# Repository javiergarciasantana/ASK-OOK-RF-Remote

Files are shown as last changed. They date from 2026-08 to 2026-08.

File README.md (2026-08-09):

# ASK-OOK-RF-Remote
Design files for my 433MHz RF remote specifically made to fit into VW Transporter T5/ Golf MK6 2 Button key fob casing.

<p align="center">

</p>

## Introduction

The *"key"* to this project is to make a functional all-in-one remote key-fob for my VW Polo 6n2. My car came from factory with a key-fob (6N0837219AC) which only had a button for a light to help you find the door or ignition lock. Said key looked like this:

<p align="center">

</p>

Additionally, my car came with a 3rd party alarm system installed from the dealer which I assume used a 433MHz additional remote with a rolling code protocol.

Nonetheless my car only had the spare key (without the light bulb) and the old alarm control unit installed behind the driver's side headlight (non UK car). Since I did not have the knowledge or expertise at the time of buying my Polo 2nd hand (I was 18), instead of getting another remote made from the existing unit, I decided to go the cheap route and buy the Aliexpress special, a 433Mhz ASK/OOK single code receiver with 2 remotes for 7EUR. [Link to the product](https://es.aliexpress.com/item/32966630703.html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)

At the time it seemed like the right choice since I wanted nothing to do with locking and unlocking my car manually (peasant things). And for a long time it was, however the first problem I noticed is that the quality of the remotes was awful, the switches degraded like crazy and I understood later that using the same single code protocol as the garage doors was not ideal. 

The remote issue I solved by getting another kind of separate remote and to this day it works like a charm after 3 years. Also and on another note, one of the best things about the receiver is that you can pair new remotes on the fly just by pressing the pairing button next to the 13 pin connector.

[Link to the other kind of remote
](https://es.aliexpress.com/item/1005008790564347.html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)<br>

---

### What problem does it solve?

Here is an image of my current key setup:




As you can see, it doesn't look half bad, however, since I am always carrying many things in my hand and other keys (plus the keychain and remote make noise everytime I hit a road bump), I wanted an all-in-one OEM+ solution. For this I started looking at Golf MK4, MK6 & MK7 remotes and decided to go with the MK6 one. I now is rather bland but its in the middle from being too futuristic(MK7) or too dingy(MK4). 





The good thing is that all remotes can share the same HU66 blade and fit on the same kind of cylinder lock, however the transponder is not the same!!! I had to install a new ID44 chip on my new key-fob. 

[Link to the 2 button Golf MK6 key-fob](https://es.aliexpress.com/item/1005005737683184.html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)

> [!IMPORTANT]
> MK4, MK5, MK6 and MK7 Golf use different transponders, going from the ID48 to the ID88

So I guess months of my life learning PCB design bit by bit would be worth it right? 
Well, for the time being I have to say yes, it was totally worth it and I learned so much in the process and got a Unique OEM+ key for my Polo out of it.

---

### Installation of the Chinese receiver
For those of you that are curious or need a wiring diagram of the OEM installation, here is a small tutorial of how I installed the receiver into my car.

#### OEM alarm 20 Pin Harness diagram

Now here I wont go much into detail, However I have to add this: the Chinese Receiver has to be put into a specific jumper configuration to be able to operate the central pneumatic system that the Polo comes standard with. Moreover, I made the mistake to not write down the wire colors but here they are detailed pin by pin:



It's not very detailed, but simply jumping the 12v with what I wanted to actuate worked, so the receiver is most likely just a big box of relays (11v in the case of the LED for some reason unknown to me).

---

Here is a connection diagram of the pins that I used on the receiver and OEM harness:



Some of them like the automatic windows did not work correctly (it was spamming like crazy). But opening and closing is a breeze and even all 6 indicators light up (one blink means close, 2 blinks is opened). 

Lastly, the OEM alarm interior light does not work with this receiver, maybe its to do with a voltage difference.


## OTP Encoding
Now to be honest, I could have designed another receiver box/module that was rolling code and could communicate and pair with Golf MK6 key-fobs, therefore integrating the automatic roll-down/up windows function or even the interior ventilation gimmick. However i was very interested in messing with this simple protocol as an RF begginer's project, so maybe in the future something like this can be made since I preserved the PCB that came with the MK6 remote.

### What is OTP Encoding?

**OTP** stands for **One-Time Programmable**. In the context of the encoder, it means the microchip contains an internal non-volatile memory layer that is permanently burned during manufacturing at the semiconductor factory with a fixed, unchangeable **20-bit identification code**.

Older RF encoders (like the classic PT2262) required 8 to 12 physical hardware pins connected to solder jumpers or DIP switches on your PCB so you could manually set a binary address. OTP encoding eliminates all of that physical configuration. Therefore, I chose the EV1527 encoder for this project as its footprint is very small and is readily available.

[EV1527 Datasheet
](./docs/EV1527.PDF)

---

### The 20-Bit Address & Possible Combinations

Every time you press a button on an EV1527 keyfob, the chip transmits a 24-bit frame:
* **20 Bits:** Factory-programmed unique address ID
* **4 Bits:** Data bits corresponding to the 4 button inputs ($K_0, K_1, K_2, K_3$)

#### Mathematical Combinations:
$$\text{Total Address Combinations} = 2^{20} = 1,048,576$$

With over 1 million unique code combinations, the probability of the keyfob sharing the exact same address code with another device nearby is roughly 1 in 1.05 million.

---

### Why OTP Encoding is the Best Choice for the Keyfob

* **Saves Board Space & Cost:** Eliminating DIP switches or solder jumper banks drastically shrinks the PCB area—allowing us to fit the EV1527 easily on the small board layout
* **Zero Serial Management During Assembly:** You don't have to program microcontrollers or keep track of serial numbers when soldering. Every EV1527 chip off the reel is guaranteed to have a different hardcoded address straight out of the box.
* **Universal Receiver Compatibility:** Modern RF receivers (learning-code receivers like the one I have) use a simple pairing button. You press "Learn" on the receiver, press your keyfob button once, and the receiver saves your unique 20-bit ID into its memory.

---

### No Crystal Needed: The Internal Oscillator & $R_{OSC}$

The EV1527 does not require a crystal oscillator, crystal load capacitors, or an external clock source.

* **Internal RC Oscillator:** The chip uses an integrated Resistor-Capacitor (RC) oscillator circuit on the silicon die.
* **Single Resistor Control:** To set the clock speed, you simply connect a single external resistor ($R_{OSC}$) between the `OSC` pin and `VCC` (typically $300\text{ k}\Omega$ to $430\text{ k}\Omega$, with $330\text{ k}\Omega$ being the standard for $433.92\text{ MHz}$ systems).
* **How It Works:** The resistance value of $R_{OSC}$ determines the charge/discharge rate of the internal oscillator, setting the timing pulse width ($T_w$) for the transmitted ASK radio signal.

## ASK/OOK Modulation

**ASK** stands for **Amplitude Shift Keying**, and **OOK** stands for **On-Off Keying**. OOK is the simplest form of ASK modulation used in low-power wireless communication.

* **How It Works:** Rather than shifting frequencies (like FM/FSK), OOK represents digital data by turning the radio transmitter **ON** and **OFF**:
  * **Binary '1' (Mark):** The transmitter turns ON and emits a full-power $433.92\text{ MHz}$ carrier wave.
  * **Binary '0' (Space):** The transmitter turns completely OFF, emitting zero radio power ($0\text{ V}$).
* **Why It Is Popular:** Because transmitting a '0' consumes virtually zero current, OOK is extremely power-efficient. Combined with low hardware complexity, it is the ideal choice for battery-powered keyfobs and garage door openers.

---

### Switching from SYN115 to CMT2110A

#### 1. The Initial Choice: SYN115
The SYN115 was initially selected because it is a widely recognized 433 MHz ASK transmitter IC. However, reviewing its datasheet revealed that it requires a significant number of external passive components to function, including crystal load capacitors, external biasing networks, and multi-stage tuning circuits, which inflates both component cost and PCB space requirements.

* **Datasheet:** [SYN115 Datasheet](./docs/SYN113-SYN115-datasheet-version-1-1-.0.pdf)

#### 2. The Solution: CMT2110A
To keep the keyfob layout compact ($37 \times 23.4\text{ mm}$), the design was shifted to the **CMT2110A**. Thanks to its high level of internal silicon integration (integrated crystal load caps, bias circuits, and internal EEPROM power control), the entire RF section requires only:

* **2 Inductors:** 
  * $L_1$ (DC supply choke)
  * $L_2$ (Series matching inductor)
* **3 Capacitors:** 
  * $C_0$ (Power decoupling filter)
  * $C_1$ (Series DC blocking capacitor)
  * $C_2$ (Shunt harmonic filter capacitor)
* **1 Quartz Crystal:** 
  * A standard 4-pin SMD $26\text{ MHz}$ crystal package (where 1 pin carries the active clock signal to the `XTAL` pin, while the remaining grounded pins provide internal shield grounding).

* **Datasheet:** [CMT2110A Datasheet](./docs/info-rf-cmt2110a-esr.pdf)

---

### Why is 433.92 MHz Used?

The $433.92\text{ MHz}$ frequency band is the dominant standard for short-range remote controls due to four key advantages:

1. **Unlicensed ISM Band:** $433.05\text{ MHz} - 434.79\text{ MHz}$ is designated worldwide as an Industrial, Scientific, and Medical (ISM) band. Devices operating under short-range, low-duty-cycle rules can transmit without requiring expensive FCC/CE user licenses.
2. **Superior Obstacle Penetration:** Sub-1 GHz signals ($433\text{ MHz}$) have longer wavelengths ($\approx 69\text{ cm}$) compared to $2.4\text{ GHz}$ (Wi-Fi/Bluetooth, $\approx 12\text{ cm}$). This allows $433\text{ MHz}$ signals to easily penetrate walls, plastic key shells, and human hands with minimal signal attenuation.
3. **Ultra-Low Battery Consumption:** At $433.92\text{ MHz}$, simple power amplifiers consume very little current ($\approx 10 - 20\text{ mA}$ during transmission), enabling years of operation on a single CR2032 coin cell.
4. **Ideal Antenna Physical Size:** A standard quarter-wave antenna at $433\text{ MHz}$ is roughly $17\text{ cm}$, which easily scales down into compact PCB trace loop antennas suitable for handheld keyfobs while maintaining reliable range ($30 - 100\text{ meters}$).

## Schema Design

Now this was perhaps one of the most challenging steps as I did not know anything about Kicad beforehand. I watched a couple videos after choosing all of my components and I was ready to go. I satarted placing symbolds, common GND and added some jumpers for the buttons, just in case, so that I can change the input in case my receiver expects a different data input (1000 instead of 0001 or 0100 instead of 0010). Which depends on what input you give power to (K0-K3).

Now since the remote requires a cr2032 holder, I added its symbol (I put is as Do not populate, this is explained in the PCB design chapter) as well as the components required by the datasheets (combination of 0402 and 0603 LED, resistors, capacitors and inductors and a 4 pin Crystal). 

The LED is required in order to know wether the remote is working or not, and I added it in the TDX-DATA line between the EV1527 and the CMT2110A



Lastly, according to the CMT2110A datasheet, the CLK pin must remain disconnected as its only used to access the embedded EEPROM and change the IC's operational frequency and other parameters



## PCB Design



This was perhaps the most stressful part, as placing the components correctly and designling an antena trace that will work on real life is very challenging
I started taking meassurements of the original board to know exactly where to place the switches and antenna components.

### Antenna design



To design an antenna, firstly we have to position these components correctly, according to the datasheet, capacitor C0 needs to be as close as possible to the RFO pin on the chip for better filtering. Now the antenna circuit by itself can look a bit complex but its really simple:

#### 1. Impedance Matching (Maximum Power Transfer)
The output pin of the IC (RFO) has a specific internal electrical impedance (often several hundred ohms). A compact PCB keyfob antenna has a completely different impedance (typically low and highly reactive, e.g., $10\ \Omega - 50\ \Omega$).If you connect the pin straight to the antenna, an impedance mismatch occurs: over 90% of the radio power reflects back into the chip instead of radiating into the air. The LC network ($L_2, C_2, C_1$) acts as an RF transformer to match the two impedances so maximum power enters the antenna.
#### 2. Harmonic Suppression (Filtering Noise)The Power Amplifier (PA) inside the chip operates like a high-speed switch. This generates the main $433.92\text{ MHz}$ signal along with unwanted square-wave harmonics at multiples of the frequency ($867.84\text{ MHz}$, $1.3\text{ GHz}$, etc.). The LC components form a low-pass filter that strips out these higher frequencies so the board complies with legal radio emission limits (CE/FCC).

#### 3. DC Power Feeding ($L_1$ Choke)The output transistor inside the CMT2110A requires DC voltage from the battery to operate. $L_1$ allows direct DC current from $V_{DD}$ to flow into the RFO pin while acting as a "wall" (high impedance) to $433.92\text{ MHz}$ RF, keeping the radio signal from leaking back into the battery line.

#### 4. DC Blocking ($C_2$)Capacitor $C_2$ sits in series right before the antenna trace. It allows $433.92\text{ MHz}$ AC radio waves to pass through to the antenna while stopping DC voltage from reaching the antenna trace, preventing short circuits if the antenna touches a grounded frame or case.

#### Antenna trace

The antenna circuit also needs a trace (or a coil). This one was designed using the **Quarter-Wave Monopole ($\lambda/4$) Rule**, adjusted for the **velocity factor** of the FR4 PCB substrate, and routed using a **Meander Line Antenna (MLA)** topology.

---

##### 1. Quarter-Wavelength ($\lambda/4$) Resonant Length
Antennas achieve optimum resonance when their physical length corresponds to one-quarter of the target RF wavelength ($\lambda/4$). 

At $433.92\text{ MHz}$, the wavelength in free space is calculated as:

$$\lambda = \frac{c}{f} = \frac{3 \times 10^8\text{ m/s}}{433.92 \times 10^6\text{ Hz}} \approx 691.4\text{ mm}$$

In open air, a standard quarter-wave antenna requires a total length of:

$$\text{Length}_{\text{air}} = \frac{691.4\text{ mm}}{4} \approx 172.8\text{ mm}$$

---

##### 2. PCB Velocity Factor Adjustment
Radio waves travel slower through an FR4 substrate ($\epsilon_r \approx 4.4$) than through open air. This effective dielectric loading introduces a **velocity factor** ($v_f \approx 0.70$), which reduces the physical trace length required to achieve $433.92\text{ MHz}$ resonance:

$$\text{Physical Trace Length} = 172.8\text{ mm} \times 0.70 \approx 120\text{ mm}$$

By designing a total trace path of **$120\text{ mm}$**, the trace electrically matches a full $172.8\text{ mm}$ quarter-wave antenna radiating in free space.

---

##### 3. Meander Line Antenna (MLA) Geometry
A straight $120\text{ mm}$ trace cannot fit across a compact $37 \times 23.4\text{ mm}$ keyfob board. 

To solve this, a **meander line pattern** (a serpentine topology consisting of 7 vertical $12\text{ mm}$ segments and 7 horizontal $3\text{ mm}$ turns) was used. This layout maintains the continuous **$120\text{ mm}$ electrical path length** needed for proper resonance while compressing the physical footprint into a small bounding box.

---

##### 4. Trace Width Selection ($1\text{ mm}$)
Unlike narrow $0.2\text{ mm}$ logic traces, a wider **$1\text{ mm}$ width** was chosen for the antenna trace for two specific reasons:

* **Lower RF Conduction Loss:** At $433.92\text{ MHz}$, high-frequency currents travel primarily on the outer surface layer of copper (*skin effect*). A wider $1\text{ mm}$ trace increases surface area, significantly reducing high-frequency resistive losses.
* **Broader Impedance Bandwidth:** Increasing trace width widens the resonant frequency band, preventing the keyfob from detuning when encapsulated inside a plastic key shell or touched by a user's hand.

##### 5. No copper fill on the back of the antenna

To prevent any interference with the signal, the antenna needs to be isolated, with as little components of signals close to it, so that no power gets harnessed from the signal.

## Breadboard Prototype



## Final Results

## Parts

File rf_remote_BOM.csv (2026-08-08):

Designator | Quantity | Value | Footprint | LCSC Part
U1 | 1 | EV1527 | Package_SO:SOIC-8_3.9x4.9mm_P1.27mm | C20539409
U2 | 1 | F115 | Package_TO_SOT_SMD:SOT-23-6 | C3010244
CR1 | 1 | 13.560MHz | Crystal:Crystal_SMD_3225-4Pin_3.2x2.5mm | C1985286
SW1,SW2 | 2 | SW_Push | Button_Switch_SMD:SW_SPST_PTS645Sx43SMTR92 | C221871
L1 | 1 | 22nH | Inductor_SMD:L_0402_1005Metric | C86129
R1 | 1 | 330k | Resistor_SMD:R_0603_1608Metric | C23137
R2 | 1 | 1k | Resistor_SMD:R_0603_1608Metric | C21190
C3 | 1 | 100NF | Capacitor_SMD:C_0603_1608Metric | C14663
D3 | 1 | Blue | LED_SMD:LED_0603_1608Metric | C2288
C1 | 1 | 1.5pF | Capacitor_SMD:C_0402_1005Metric | C1552

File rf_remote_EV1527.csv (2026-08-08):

Reference | Value | Footprint | Part No
U3 | CR2032 | Battery:BatteryHolder_Keystone_3002_1x2032 | DNP
JP1,JP2 | Jumper_3_Open | Jumper:SolderJumper-3_P1.3mm_Open_RoundedPad1.0x1.5mm | DNP
AE1 | Antenna | TestPoint:TestPoint_Pad_1.0x1.0mm | DNP
U1 | EV1527 | Package_SO:SOIC-8_3.9x4.9mm_P1.27mm | C20539409
U2 | F115 | Package_TO_SOT_SMD:SOT-23-6 | C3010244
CR1 | 13.560MHz | Crystal:Crystal_SMD_3225-4Pin_3.2x2.5mm | C1985286
SW1,SW2 | SW_Push | Button_Switch_SMD:SW_SPST_PTS645Sx43SMTR92 | C221871
L1 | 22nH | Inductor_SMD:L_0402_1005Metric | C86129
R1 | 330k | Resistor_SMD:R_0603_1608Metric | C23137
R2 | 1k | Resistor_SMD:R_0603_1608Metric | C21190
C3 | 100NF | Capacitor_SMD:C_0603_1608Metric | C14663
D3 | LED | LED_SMD:LED_0603_1608Metric | C2288
C1 | 1.5pF | Capacitor_SMD:C_0402_1005Metric | C1552

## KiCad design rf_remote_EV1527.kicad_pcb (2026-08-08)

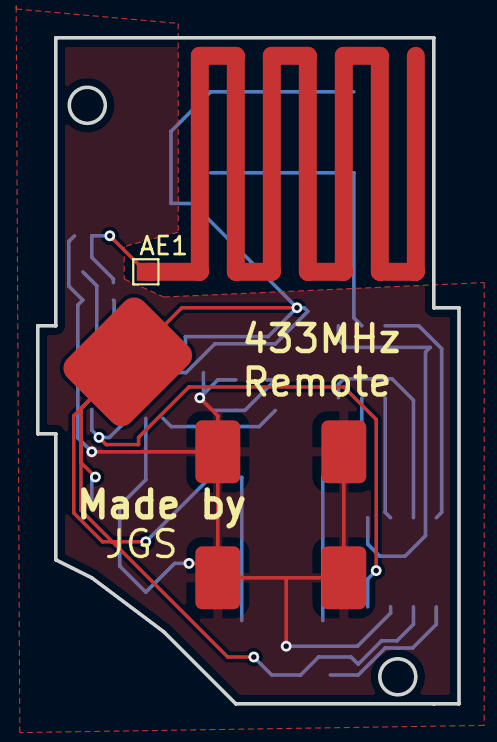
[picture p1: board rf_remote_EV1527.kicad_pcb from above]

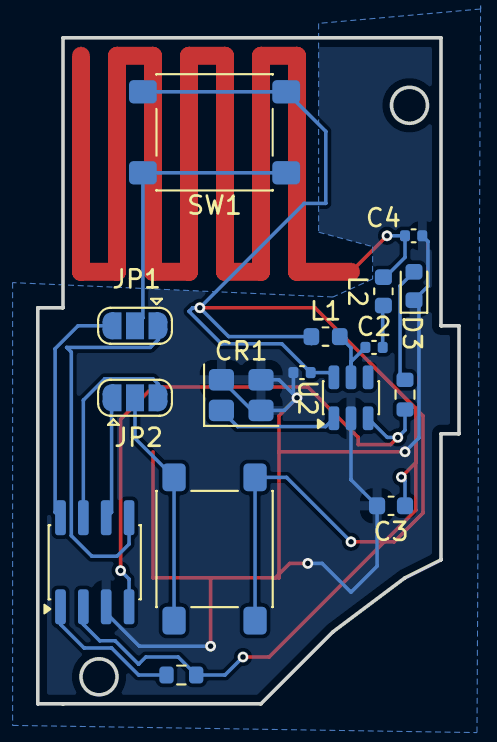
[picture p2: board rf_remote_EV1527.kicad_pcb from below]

Board: 2 copper layers, 23.4 x 37.0 mm, 18 parts (16 on the bottom side), 15 nets.

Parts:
AE1: Antenna; TestPoint_Pad_1.0x1.0mm
C1: 0.1uF; C_0402_1005Metric
C2: 82pF; C_0402_1005Metric
C3: 100NF; C_0603_1608Metric
C4: 9pF; C_0402_1005Metric
CR1: 26 MHz; Crystal_SMD_3225-4Pin_3.2x2.5mm
D3: LED; LED_0603_1608Metric
JP1, JP2: Jumper_3_Open; SolderJumper-3_P1.3mm_Open_RoundedPad1.0x1.5mm
L1: 180nH; L_0603_1608Metric
L2: 27nH; L_0603_1608Metric
R1: 330k; R_0603_1608Metric
R2: 1k; R_0603_1608Metric
SW1, SW2: SW_Push; SW_SPST_PTS645Sx43SMTR92
U1: EV1527; SOIC-8_3.9x4.9mm_P1.27mm
U2: CMT2110A; SOT-23-6
U3: CR2032; BatteryHolder_Keystone_3002_1x2032

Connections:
GND: C1.2, C3.2, C4.2, CR1.2, CR1.3, CR1.4, D3.1 (K), U1.3 (VSS), U2.2 (GND), U3.-
unnamed: AE1.1 (A), C4.1, L2.2
unnamed: C2.2, L2.1
unnamed: D3.2 (A), R2.1
unnamed: JP1.1 (A), U1.5 (K0)
unnamed: JP1.3 (B), U1.8 (K3)
unnamed: JP1.2 (C), SW1.1
unnamed: JP2.1 (A), U1.6 (K1)
unnamed: JP2.3 (B), U1.7 (K2)
unnamed: JP2.2 (C), SW2.1
unnamed: R1.2, U1.1 (OSC)
unnamed: R2.2, U1.4 (TXD), U2.3 (DATA)
unnamed: C1.1, C3.1, L1.1, R1.1, SW1.2, SW2.2, U1.2 (VCC), U2.6 (VDD), U3.+1
unnamed: C2.1, L1.2, U2.5 (RFO)
unnamed: CR1.1, U2.1 (XTAL)

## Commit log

2026-08-08 Project Files Added
    [rf_remote_BOM.csv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]
2026-08-09 missing prototype
